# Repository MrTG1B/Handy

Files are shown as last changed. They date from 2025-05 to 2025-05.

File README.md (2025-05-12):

# Handy: An Affordable Myoelectric Prosthetic Hand

Welcome to the official repository for **Handy**, an affordable myoelectric prosthetic hand designed for accessibility, modularity, and ease of assembly. This repository includes all the essential files and code necessary to build and control Handy, including hardware design files, embedded firmware, and a multimedia app interface.

---

## Repository Structure

```
Handy/
├── App/                # Android app source code for controlling Handy
├── Design Files/       # STL and CAD files for 3D printing Handy's mechanical parts
├── ESP32 Code/         # Firmware for the ESP32 microcontroller
├── Multimedia/         # Demo videos, project posters, and presentation materials
├── Images/             # Visual references and assembled prototype images
├── README.md           # Project overview and documentation
```

---

## Features

* **Affordable**: Designed using low-cost components and open-source tools.
* **Myoelectric Controlled**: Uses EMG signals to control prosthetic movement.
* **Wireless Interface**: ESP32-powered wireless control via a custom Android app.
* **Customizable Design**: STL files provided for 3D printing and customization.
* **Open-Source**: All design files, code, and documentation are freely available.

---

## Getting Started

### 1. Hardware Assembly

* 3D print components from the `Design Files/` directory.
* Follow the provided images in `Images/` for reference.
* Assemble the hand and integrate EMG sensors, servo motors, and ESP32.

### 2. Firmware Installation

* Flash the code from the `ESP32 Code/` directory to your ESP32 board.
* Make sure to configure the correct pins and WiFi credentials.

### 3. App Setup

* Clone the `App/` directory into Android Studio.
* Build and install the app on an Android phone.
* Connect the app to the ESP32 via WiFi.

---

## Multimedia

* Check the `Multimedia/` directory for:

  * Demo videos of Handy in action
  * Posters and presentations for exhibitions and competitions

---

## Contributing

Feel free to fork the repository and suggest improvements via pull requests. Whether it's hardware design, code optimization, or UI enhancements — your contributions are welcome!

---

## License

This project is licensed under the MIT License — see the `LICENSE` file for details.

---

## Contact

Created by [MrTG1B](https://github.com/MrTG1B). For questions or collaboration, please raise an issue or contact via GitHub.

---

Thank you for your interest in Handy — empowering lives with accessible technology!

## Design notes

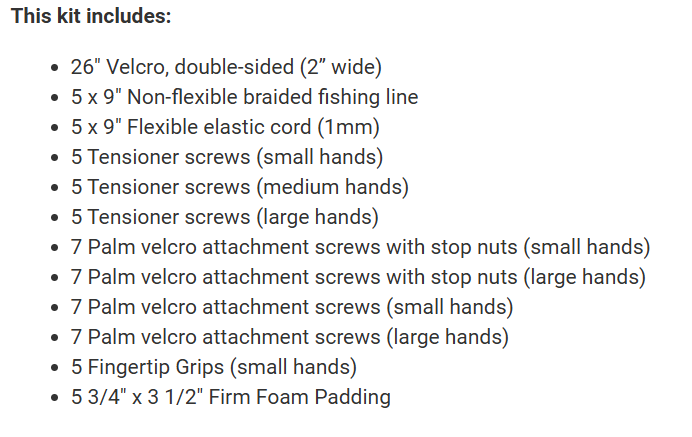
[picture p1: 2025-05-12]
MultiMedia/Screenshot 2025-05-12 144004.png

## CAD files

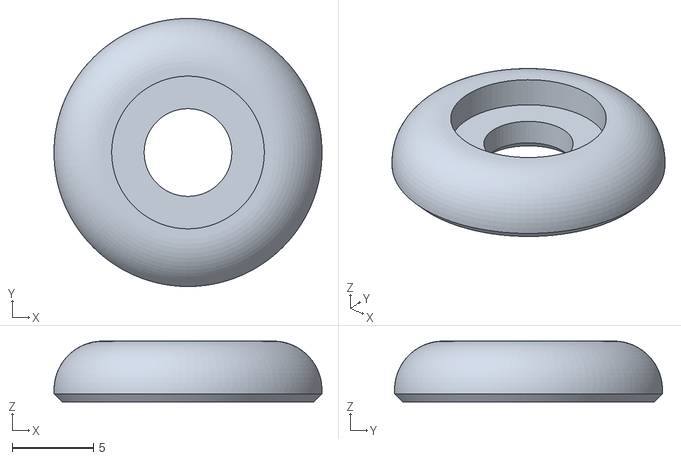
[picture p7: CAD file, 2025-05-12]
Design/STL_Files/Wrist pin cap.stl
16.5 x 16.5 x 3.75

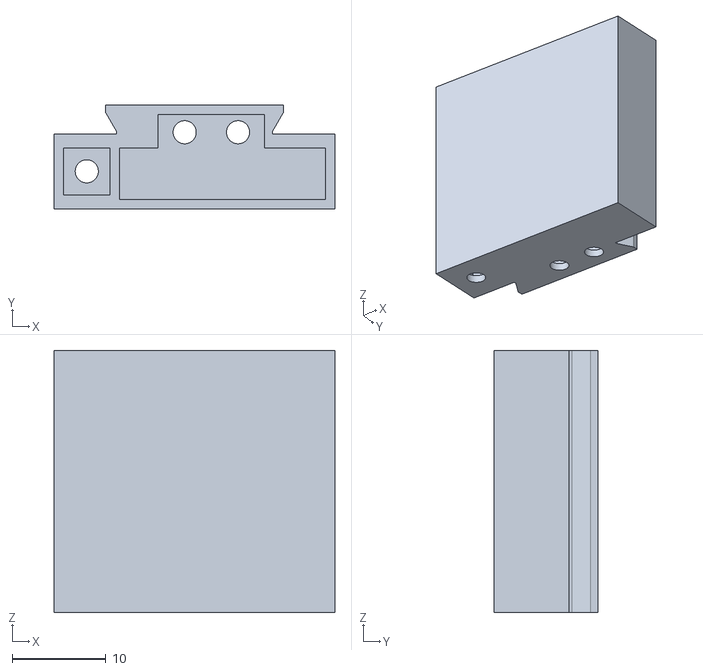
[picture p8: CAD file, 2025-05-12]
Design/STL_Files/Gripper box right.stl
30.0 x 11.1 x 28.0

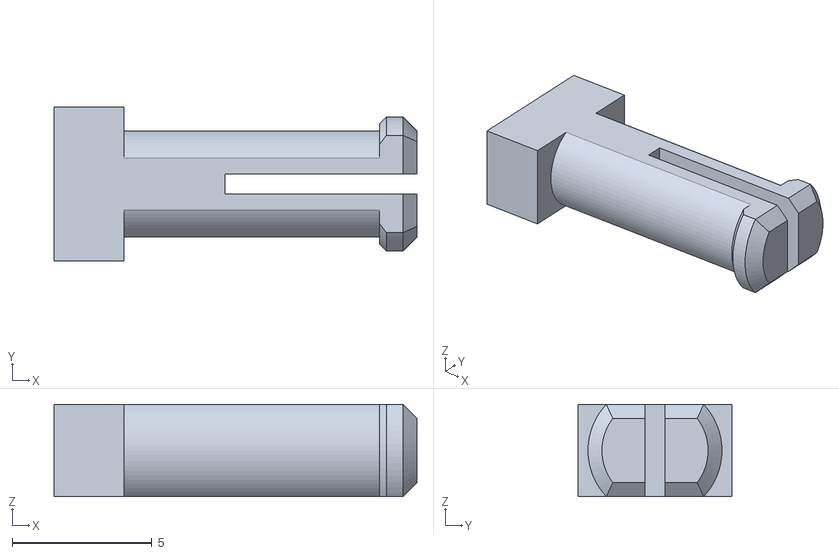
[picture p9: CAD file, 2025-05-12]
Design/STL_Files/Knuckle pin short.stl
13.0 x 5.50 x 3.30

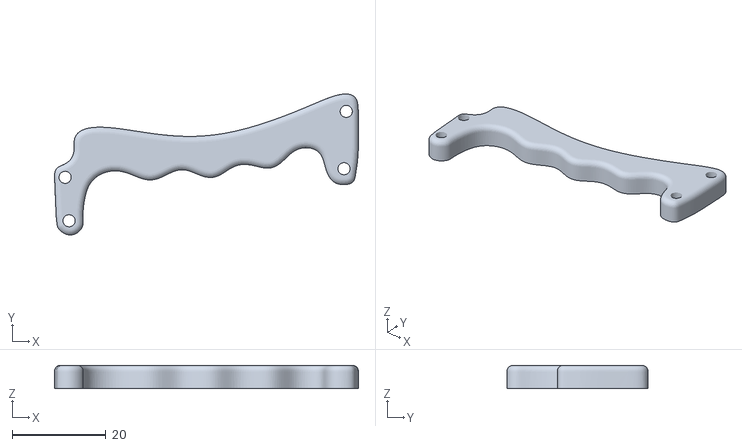
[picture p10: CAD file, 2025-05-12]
Design/STL_Files/Phoenix Right Demo Bar.stl
64.9 x 30.1 x 5.00

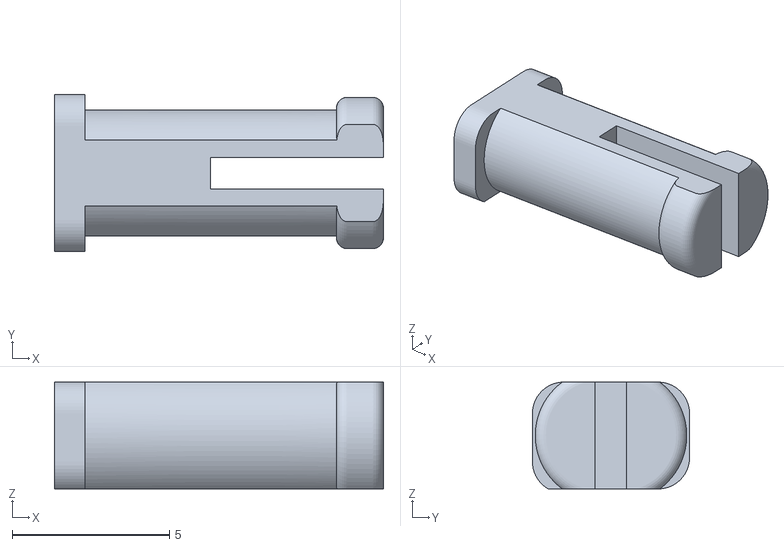
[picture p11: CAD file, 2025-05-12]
Design/STL_Files/Fingertip pin.stl
10.5 x 5.00 x 3.40

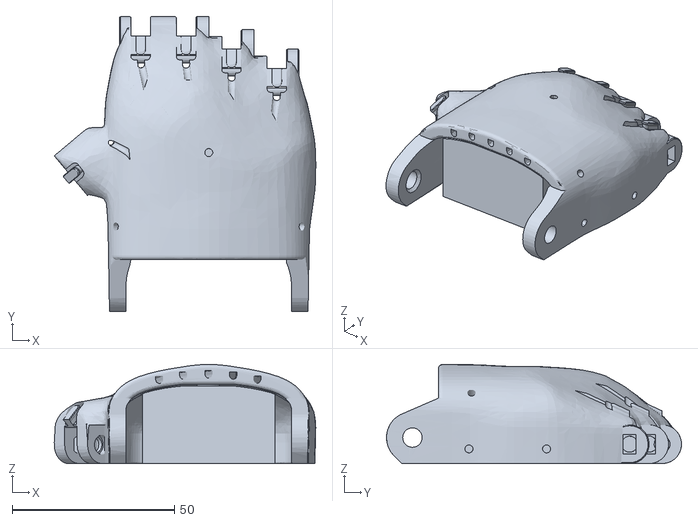
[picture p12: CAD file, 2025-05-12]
Design/STL_Files/Palm right new supports.stl
80.6 x 91.0 x 30.6

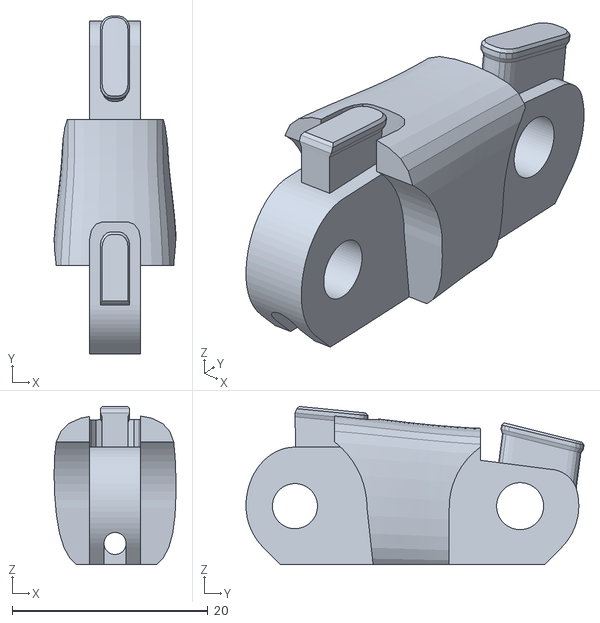
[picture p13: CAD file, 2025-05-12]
Design/STL_Files/finger_phalanx.stl
12.4 x 34.5 x 16.2

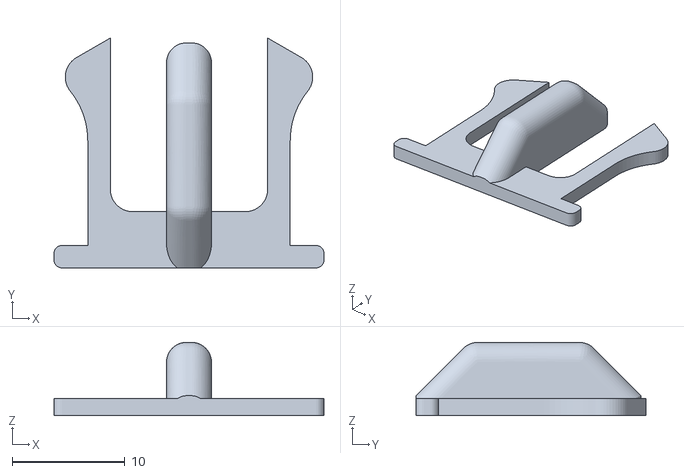
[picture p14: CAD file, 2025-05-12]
Design/STL_Files/Retention clip.stl
24.0 x 20.4 x 6.50

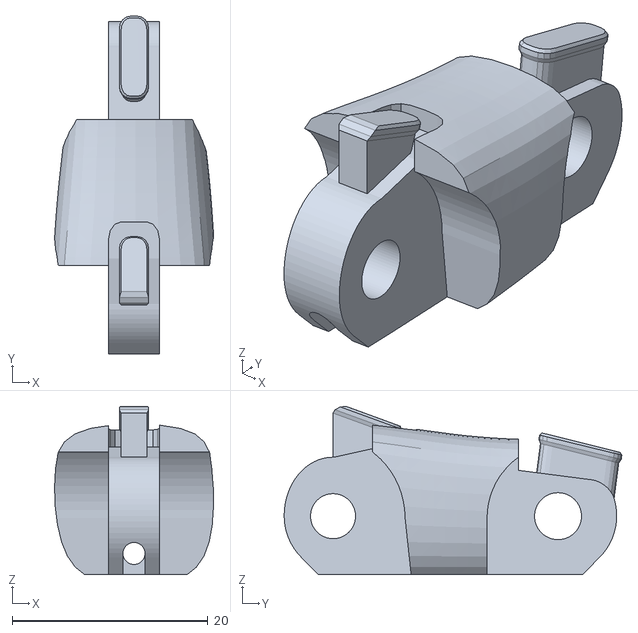
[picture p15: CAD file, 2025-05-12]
Design/STL_Files/Thumb phalanx.stl
16.3 x 34.5 x 17.2

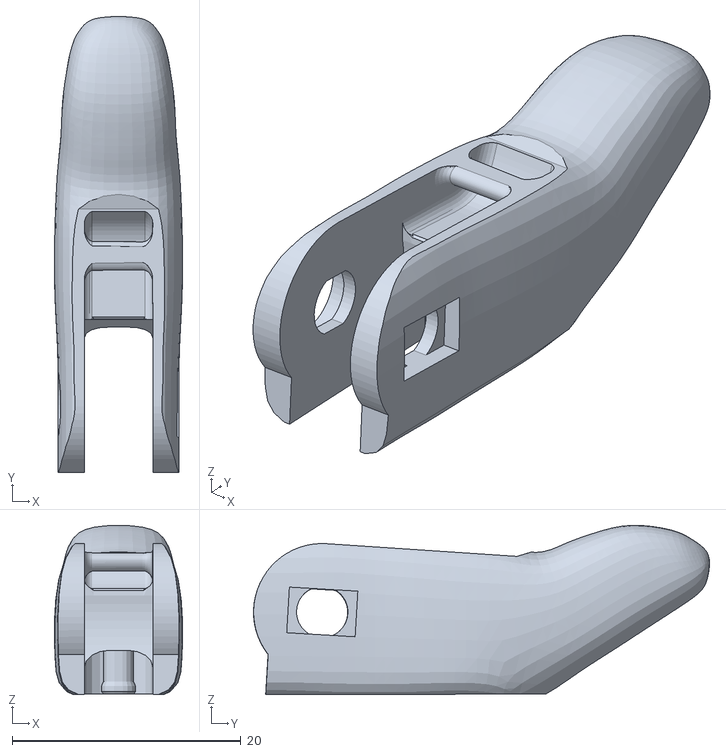
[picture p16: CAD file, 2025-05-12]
Design/STL_Files/Fingertip short.stl
11.2 x 39.9 x 14.8

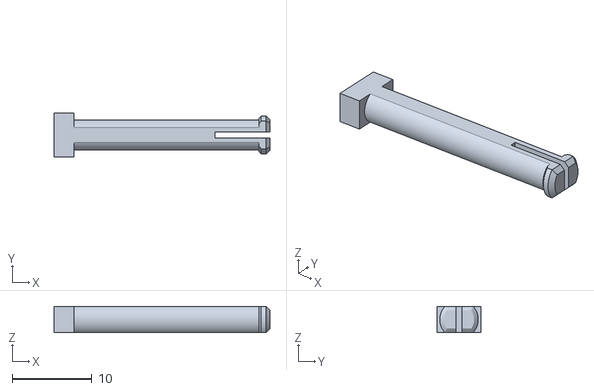
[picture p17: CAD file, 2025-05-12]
Design/STL_Files/Knuckle pin long.stl
27.0 x 5.50 x 3.30

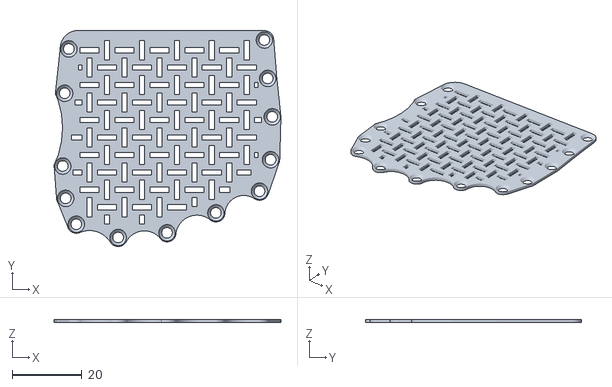
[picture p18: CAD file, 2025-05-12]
Design/STL_Files/Palm mesh right thin.stl
65.0 x 61.9 x 1.00

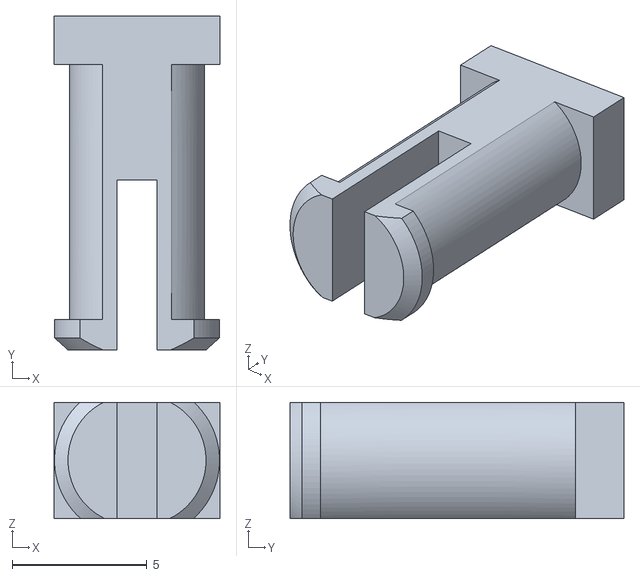
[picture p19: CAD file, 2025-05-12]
Design/STL_Files/Wrist pin thermo.stl
6.15 x 12.4 x 4.30

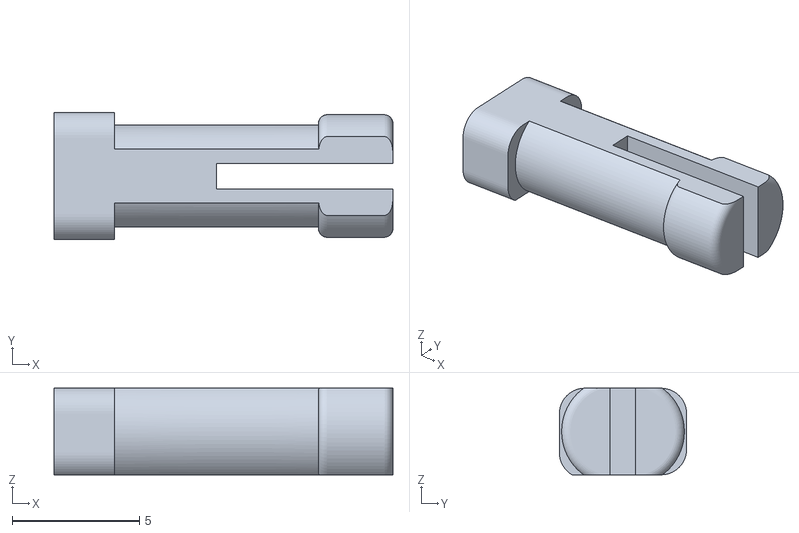
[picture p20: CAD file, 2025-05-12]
Design/STL_Files/Thumbtip pin.stl
13.3 x 5.00 x 3.40

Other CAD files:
Design/STL_Files/Whippletree.stl
Design/STL_Files/Swivel pin right.stl
Design/STL_Files/Palm mesh right thick.stl
Design/STL_Files/Thumbtip.stl
Design/STL_Files/Fingertip long.stl
Design/STL_Files/Thermo gauntlet two strap one_row.stl
Design/STL_Files/Thumb tensioner pin.stl

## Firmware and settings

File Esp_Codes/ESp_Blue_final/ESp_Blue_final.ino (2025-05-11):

#include <ESP32Servo.h>  // Use the ESP32Servo library
#include "HardwareSerial.h"

// Create a second hardware serial object for HM-10
HardwareSerial HM10(2); // Use UART2, which is GPIO16 (RX2) and GPIO17 (TX2)

// Number of servos
const int NUM_SERVOS = 8;

// Servo array
Servo servos[NUM_SERVOS];

// Servo pins array
const int servoPins[NUM_SERVOS] = {13, 12, 14, 27, 26, 25, 33, 15}; // 8th servo on pin 15

// FSR and Motor Pins
const int numFSRs = 4;
const int fsrPins[numFSRs] = {32, 35, 34, 36};     // FSR pins array
const int motorPins[numFSRs] = {4, 5, 18, 19};     // Motor pins array

// EMG sensor pin and threshold
const int emgPin = 39;
const int emgThreshold = 3000;

// Thresholds
const int fsrThreshold = 500;  // Adjust based on your FSR sensitivity

//wrist angle
int wristSwingAngle=90;
int wristRotateAngle=90;

// Bluetooth setup (using Serial2 for communication)
#define RXD2 16
#define TXD2 17

bool commandExecuted = false;

String commandData="";

typedef void (*CommandFunction)();

void setup() {
  // Attach servos to their respective pins
  for (int i = 0; i < NUM_SERVOS; i++) {
    servos[i].attach(servoPins[i]);
  }

  // Initialize motor pins as outputs
  for (int i = 0; i < numFSRs; i++) {
    pinMode(motorPins[i], OUTPUT);
    digitalWrite(motorPins[i], LOW);  // Start with motors off
  }

  // Initialize EMG pin as input
  pinMode(emgPin, INPUT);

  // Initialize serial communication for HM-10 and debugging
  Serial.begin(115200);                        // Debugging on Serial Monitor
  HM10.begin(9600, SERIAL_8N1, RXD2, TXD2); // HM-10 on Serial2 (Pins 16 and 17)

  Serial.println("Waiting for Bluetooth data...");
}

void loop() {
  // Check for available data from Bluetooth
  if (HM10.available()) {
    commandData = HM10.readString(); // Read incoming character
    Serial.println("Stored command: " + commandData); 
    if ((commandData=="9")||(commandData=="10")||(commandData=="11")||(commandData=="12"))
    {
      executeCommand(commandData);
    }
  }

  // Handle FSR readings and control vibration motors
  for (int i = 0; i < numFSRs; i++) {
    int fsrValue = analogRead(fsrPins[i]);

    // Map FSR values to motor intensity (0-255 for PWM control)
    int motorIntensity = map(fsrValue, fsrThreshold, 4095, 0, 255); // Adjust 4095 if using a 10-bit ADC
    motorIntensity = constrain(motorIntensity, 0, 255); // Constrain to valid PWM range

    analogWrite(motorPins[i], motorIntensity); // Set motor intensity based on FSR value
  }
  
  // Check EMG data
  checkEmgData();
  delay(500);
}

void checkEmgData() {
  int emgData = analogRead(emgPin);
  Serial.println(emgData);
  if (emgData > emgThreshold) {
    if (commandExecuted==false) {
      executeCommand(commandData);
      commandExecuted = true;
      Serial.println("commandExecuted");
      
    } else if (commandExecuted==true) {
      openAllServos();
      commandExecuted = false;  // Reset for the next command
    }
  }
}

void openAllServos() {
  for (int i = 0; i < 5; i++) {  // Only set the first five servos
    servos[i].write(0);  // Set each of the first five servos to 0 degrees
  }
  for (int i=5;i<NUM_SERVOS;i++){
    servos[i].write(90);
  }
  Serial.println("First five servos opened to 0 degrees.");
}

void swing(Servo &myServo, int startPos, int endPos, int delayTime) {
  if (startPos < endPos) {
    for (int pos = startPos; pos <= endPos; pos++) {
      myServo.write(pos);
      delay(delayTime);
    }
  } else {
    for (int pos = startPos; pos >= endPos; pos--) {
      myServo.write(pos);
      delay(delayTime);
    }
  }
}

// Command functions
void func1() {
  for (int i = 0; i < 5; i++) { servos[i].write(90); }
  servos[5].write(90); // Wrist swing
  servos[6].write(0);  // Wrist rotate
}

void func2() {
  servos[0].write(0); 
  for (int i = 1; i < 5; i++) { servos[i].write(180); }
  servos[5].write(90); // Wrist swing
  servos[6].write(0);  // Wrist rotate
}

void func3() {
  servos[0].write(180); 
  servos[1].write(45);
  servos[2].write(90);
  servos[3].write(135);
  servos[4].write(180);
  servos[5].write(90); // Wrist swing
  servos[6].write(90); // Wrist rotate
}

void func4() {
  servos[0].write(180);
  for (int i = 1; i < 5; i++) { servos[i].write(30); }
  servos[5].write(0);  // Wrist swing
  servos[6].write(0);  // Wrist rotate
}

void func5() {
  for (int i = 0; i < 5; i++) { servos[i].write(180); }
  servos[5].write(90); // Wrist swing
  servos[6].write(90); // Wrist rotate
}

void func6() {
  for (int i = 0; i < 5; i++) { servos[i].write(180); }
  servos[5].write(90); // Wrist swing
  servos[6].write(90); // Wrist rotate
}

void func7() {
  for (int i = 0; i < 5; i++) { servos[i].write(180); }
  servos[5].write(90); // Wrist swing
  servos[6].write(90); // Wrist rotate
}

void func8() {
  for (int i = 0; i < 5; i++) { servos[i].write(180); }
  servos[5].write(90); // Wrist swing
  servos[6].write(90); // Wrist rotate
}

void func9(){
  wristSwingAngle=wristSwingAngle+90;
  servos[5].write(wristSwingAngle);
}

void func10(){
  wristSwingAngle=wristSwingAngle-90;
  servos[5].write(wristSwingAngle);
}

void func11(){
  wristRotateAngle=wristRotateAngle+90;
  servos[6].write(wristRotateAngle);
}

void func12(){
  wristRotateAngle=wristRotateAngle-90;
  servos[6].write(wristRotateAngle);
}

void func13(){
  servos[0].write(180);
  servos[2].write(180);
  servos[3].write(180);
  servos[1].write(0);
  servos[4].write(0);
}

void func14(){
  for(int i=0;i<5;i++)
  {
    servos[i].write(180);
  }
  delay(100);
  servos[2].write(0);
}



// Array of function pointers
CommandFunction functions[] = {
  func1, func2, func3, func4, func5, func6, func7,
  func8, func9, func10, func11, func12, func13, func14
};


void executeCommand(String command) {
  int index = command.toInt();  // Convert string to integer
  // Note: In Arduino, use sizeof(functions)/sizeof(functions[0]) instead of .length()
  if (index >= 1 && index <= sizeof(functions)/sizeof(functions[0])) {
    functions[index - 1]();  // Arrays are 0-based, so subtract 1
  } else {
    Serial.println("Unknown command received.");
  }
  // commandData="";
}

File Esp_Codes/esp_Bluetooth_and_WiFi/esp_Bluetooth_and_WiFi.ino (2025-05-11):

#include <WiFi.h>
#include <ESP32Servo.h>  // Use the ESP32Servo library instead of the standard Servo library

// Wi-Fi credentials
const char* ssid = "Tirthankar";
const char* password = "Dasgupta2004";

// Servo objects
Servo servo1, servo2, servo3, servo4, servo5, servo6, servo7;

// Servo pins
const int servoPin1 = 13;
const int servoPin2 = 12;
const int servoPin3 = 14;
const int servoPin4 = 27;
const int servoPin5 = 26;
const int servoPin6 = 25;
const int servoPin7 = 33;

// FSR pins (Analog inputs)
const int fsrPin1 = 32;
const int fsrPin2 = 35;
const int fsrPin3 = 34;
const int fsrPin4 = 36;

// Vibration motor pins (Reassigned to different pins)
const int motorPin1 = 4;  // Changed from 16 to 4
const int motorPin2 = 5;  // Changed from 17 to 5
const int motorPin3 = 18;
const int motorPin4 = 19;

// FSR threshold for motor activation
const int fsrThreshold = 500;  // Adjust based on your FSR sensitivity

WiFiServer server(80);  // Initialize the server on port 80

// Bluetooth communication using HM-10 module on pins 16 (RX) and 17 (TX)
HardwareSerial BTSerial(2);  // Use UART2 for Bluetooth (RX on 16, TX on 17)

void setup() {
  // Initialize servos
  servo1.attach(servoPin1);
  servo2.attach(servoPin2);
  servo3.attach(servoPin3);
  servo4.attach(servoPin4);
  servo5.attach(servoPin5);
  servo6.attach(servoPin6);
  servo7.attach(servoPin7);

  // Initialize motor pins as outputs
  pinMode(motorPin1, OUTPUT);
  pinMode(motorPin2, OUTPUT);
  pinMode(motorPin3, OUTPUT);
  pinMode(motorPin4, OUTPUT);

  // Start with motors off
  digitalWrite(motorPin1, LOW);
  digitalWrite(motorPin2, LOW);
  digitalWrite(motorPin3, LOW);
  digitalWrite(motorPin4, LOW);

  // Connect to Wi-Fi
  Serial.begin(115200);
  WiFi.begin(ssid, password);
  while (WiFi.status() != WL_CONNECTED) {
    delay(1000);
    Serial.println("Connecting to WiFi...");
  }
  
  // Print IP address
  Serial.print("Connected to WiFi. IP Address: ");
  Serial.println(WiFi.localIP());

  // Start the server
  server.begin();

  // Initialize HM-10 Bluetooth communication
  BTSerial.begin(9600, SERIAL_8N1, 16, 17);  // Baud rate: 9600, RX: 16, TX: 17
  Serial.println("Bluetooth module ready");
}

void loop() {
  // Handle incoming client requests (via WiFi)
  WiFiClient client = server.available();
  if (client) {
    String request = client.readStringUntil('\r');
    client.flush();

    // Parse the incoming request (e.g., "servo1:90")
    if (request.startsWith("servo1:")) {
      int angle = request.substring(7).toInt();
      servo1.write(angle);
    } else if (request.startsWith("servo2:")) {
      int angle = request.substring(7).toInt();
      servo2.write(angle);
    } else if (request.startsWith("servo3:")) {
      int angle = request.substring(7).toInt();
      servo3.write(angle);
    } else if (request.startsWith("servo4:")) {
      int angle = request.substring(7).toInt();
      servo4.write(angle);
    } else if (request.startsWith("servo5:")) {
      int angle = request.substring(7).toInt();
      servo5.write(angle);
    } else if (request.startsWith("servo6:")) {
      int angle = request.substring(7).toInt();
      servo6.write(angle);
    } else if (request.startsWith("servo7:")) {
      int angle = request.substring(7).toInt();
      servo7.write(angle);
    }

    // Send a proper HTTP response to the client
    client.println("HTTP/1.1 200 OK");
    client.println("Content-Type: text/plain");
    client.println("Connection: close");  // The connection will be closed after completion of the response
    client.println();  // Empty line to indicate the end of headers
    client.println("Command received");

    delay(1);  // Allow time for the client to receive the data
    client.stop();  // Close the connection
  }

  // Handle FSR readings and control vibration motors
  int fsrValue1 = analogRead(fsrPin1);
  int fsrValue2 = analogRead(fsrPin2);
  int fsrValue3 = analogRead(fsrPin3);
  int fsrValue4 = analogRead(fsrPin4);

  digitalWrite(motorPin1, (fsrValue1 > fsrThreshold) ? HIGH : LOW);
  digitalWrite(motorPin2, (fsrValue2 > fsrThreshold) ? HIGH : LOW);
  digitalWrite(motorPin3, (fsrValue3 > fsrThreshold) ? HIGH : LOW);
  digitalWrite(motorPin4, (fsrValue4 > fsrThreshold) ? HIGH : LOW);

  delay(100);  // Small delay for stability

  // Bluetooth communication handling
  if (BTSerial.available()) {
    String btCommand = BTSerial.readStringUntil('\n');
    btCommand.trim();  // Remove any trailing newline characters

    Serial.print("Received via Bluetooth: ");
    Serial.println(btCommand);

    // Handle Bluetooth commands to control servos, motors, or other components
    if (btCommand.startsWith("servo1:")) {
      int angle = btCommand.substring(7).toInt();
      servo1.write(angle);
    } else if (btCommand.startsWith("servo2:")) {
      int angle = btCommand.substring(7).toInt();
      servo2.write(angle);
    } else if (btCommand.startsWith("servo3:")) {
      int angle = btCommand.substring(7).toInt();
      servo3.write(angle);
    } else if (btCommand.startsWith("servo4:")) {
      int angle = btCommand.substring(7).toInt();
      servo4.write(angle);
    } else if (btCommand.startsWith("servo5:")) {
      int angle = btCommand.substring(7).toInt();
      servo5.write(angle);
    } else if (btCommand.startsWith("servo6:")) {
      int angle = btCommand.substring(7).toInt();
      servo6.write(angle);
    } else if (btCommand.startsWith("servo7:")) {
      int angle = btCommand.substring(7).toInt();
      servo7.write(angle);
    }
  }
}

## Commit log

2025-05-11 Add initial project files and implement core functionality
    - Created manifest.json for PWA support with app details and icons.
    - Added script.js to handle UI interactions and Bluetooth connectivity for the prosthetic hand.
    - Implemented service worker in service-worker.js for caching and offline support.
    - Developed style.css for styling the application with responsive design.
    - Added multimedia assets including favicon.ico and logo.ico for branding.
    - Configured desktop.ini for custom folder icon.
    [servoConfig.json]
2025-05-12 Refactor code structure for improved readability and maintainability
    [Fingertip long.stl, Fingertip pin.stl, Fingertip short.stl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]
